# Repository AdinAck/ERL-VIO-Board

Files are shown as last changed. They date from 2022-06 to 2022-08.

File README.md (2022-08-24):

# ERL-VIO-Board
A small board intended for cleaning up the VIO sets, providing power options, and connecting the cameras and IMU.

# **WARNING**

**v1.0 has a silk screen error for the external supply port. - should be + and + should be -**

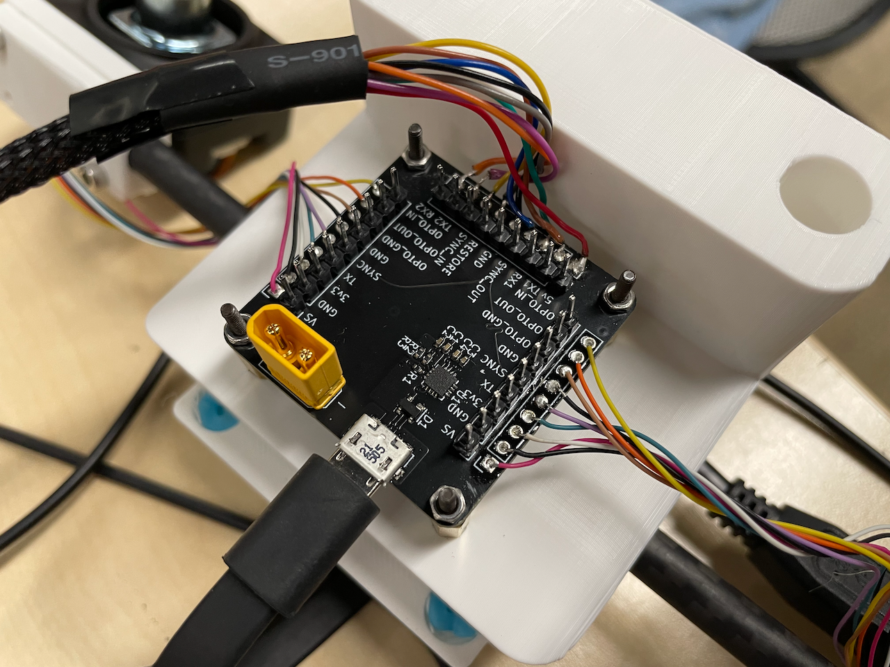
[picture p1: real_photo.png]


## Project Goal
Make it as easy and fast as possible to swap out cameras or IMU, and to diagnose problems.

## Features
- Verbose connectivity for IMU and cameras
- USB to UART bridge for IMU
- `SYNC` connection between IMU and cameras
- Optional external supply for cameras

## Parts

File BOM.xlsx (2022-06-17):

Table 1
Reference | Value | Footprint | Datasheet | Mouser | Quantity
> C1, C4 | 4u7 | Capacitor_SMD:C_0402_1005Metric | https://www.mouser.com/datasheet/2/281/1/GRM155R60J475ME87_01A-1983790.pdf | https://www.mouser.com/ProductDetail/Murata-Electronics/GRM155R60J475ME87D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 | 2
> C2, C3 | 100n | Capacitor_SMD:C_0402_1005Metric | https://www.mouser.com/datasheet/2/281/1/GRM155R71A104KA01_01A-1983947.pdf | https://www.mouser.com/ProductDetail/Murata-Electronics/GRM155R71A104KA01J | 2
D1 | SP0503BAHT | Package_TO_SOT_SMD:SOT-143 | http://www.littelfuse.com/~/media/files/littelfuse/technical%20resources/documents/data%20sheets/sp05xxba.pdf | https://www.mouser.com/ProductDetail/Littelfuse/SP0503BAHTG?qs=uD%2FdkN7XIa0NTYXwHdELYA%3D%3D | 1
J1 | Conn_01x02_Female | Connector_AMASS:AMASS_XT30U-F_1x02_P5.0mm_Vertical | ~ |  | 1
J2 | USB_B_Micro | Connector_USB:USB_Micro-B_Molex_47346-0001 | ~ | https://www.mouser.com/ProductDetail/Molex/47346-0001?qs=c2CV6XM0DweJBWaSeyWeCw%3D%3D | 1
> J3-J5 | Conn_01x09_Male | Connector_PinHeader_2.54mm:PinHeader_1x09_P2.54mm_Vertical | ~ |  | 3
> J6-J8 | Conn_01x09_Female | Connector_PinSocket_2.54mm:PinSocket_1x09_P2.54mm_Vertical | ~ |  | 3
R1 | 5k1 | Resistor_SMD:R_0402_1005Metric | https://www.mouser.com/datasheet/2/315/AOA0000C301-1488782.pdf | https://www.mouser.com/ProductDetail/Panasonic/ERJ-2RKF5101X?qs=sGAEpiMZZMvdGkrng054t8AJgcdMkx7xIXmurKOGv8o%3D | 1
R2 | 22k1 | Resistor_SMD:R_0402_1005Metric | ~ | https://www.mouser.com/ProductDetail/Panasonic/ERJ-2RKF2212X?qs=sGAEpiMZZMvdGkrng054t12mw2BDkjbP8o5TRFWNk6o%3D | 1
R3 | 47k5 | Resistor_SMD:R_0402_1005Metric | ~ | https://www.mouser.com/ProductDetail/Panasonic/ERJ-2RKF4752X | 1
U1 | CP2102N-Axx-xQFN20 | Package_DFN_QFN:SiliconLabs_QFN-20-1EP_3x3mm_P0.5mm_EP1.8x1.8mm | https://www.silabs.com/documents/public/data-sheets/cp2102n-datasheet.pdf | https://www.mouser.com/ProductDetail/Silicon-Labs/CP2102N-A02-GQFN20?qs=u16ybLDytRaG8WdlP0fT2g%3D%3D | 1

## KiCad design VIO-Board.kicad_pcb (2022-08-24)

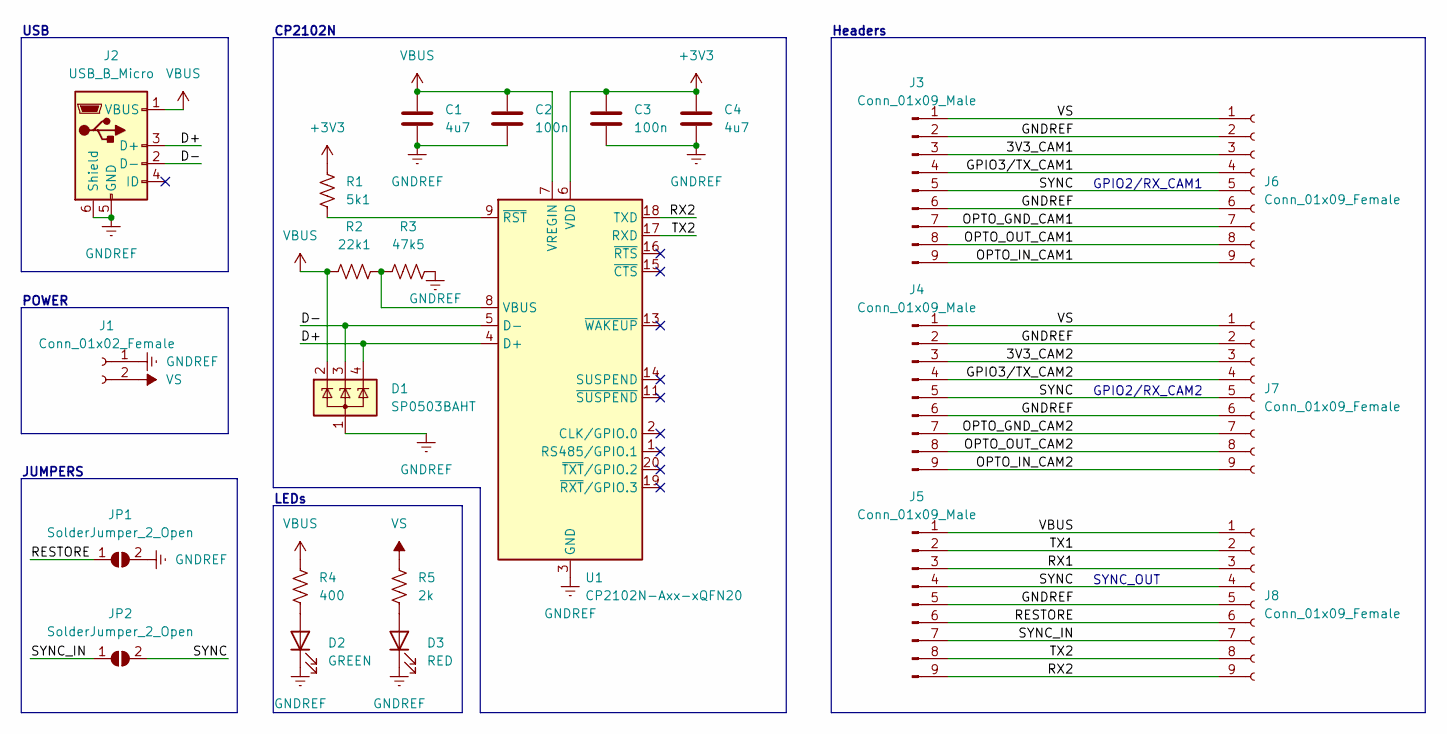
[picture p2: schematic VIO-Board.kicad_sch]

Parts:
C1, C4: 4u7; C_0402_1005Metric
C2, C3: 100n; C_0402_1005Metric
D1: SP0503BAHT; SOT-143
D2: GREEN; LED_0603_1608Metric
D3: RED; LED_0603_1608Metric
J1: Conn_01x02_Female; AMASS_XT30U-F_1x02_P5.0mm_Vertical
J2: USB_B_Micro; USB_Micro-B_Molex_47346-0001
J3, J4, J5: Conn_01x09_Male; PinHeader_1x09_P2.54mm_Vertical
J6, J7, J8: Conn_01x09_Female; PinSocket_1x09_P2.54mm_Vertical
JP1, JP2: SolderJumper_2_Open; SolderJumper-2_P1.3mm_Open_RoundedPad1.0x1.5mm
R1: 5k1; R_0402_1005Metric
R2: 22k1; R_0402_1005Metric
R3: 47k5; R_0402_1005Metric
R4: 400; R_0402_1005Metric
R5: 2k; R_0402_1005Metric
U1: CP2102N-Axx-xQFN20; SiliconLabs_QFN-20-1EP_3x3mm_P0.5mm_EP1.8x1.8mm

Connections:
+3V3: C3.1, C4.1, R1.1, U1.6 (VDD)
/3V3_CAM1: J3.3, J6.3
/3V3_CAM2: J4.3, J7.3
/D+: D1.4 (K), J2.3 (D+), U1.4 (D+)
/D-: D1.3 (K), J2.2 (D-), U1.5 (D-)
/GPIO3/TX_CAM1: J3.4, J6.4
/GPIO3/TX_CAM2: J4.4, J7.4
/OPTO_GND_CAM1: J3.7, J6.7
/OPTO_GND_CAM2: J4.7, J7.7
/OPTO_IN_CAM1: J3.9, J6.9
/OPTO_IN_CAM2: J4.9, J7.9
/OPTO_OUT_CAM1: J3.8, J6.8
/OPTO_OUT_CAM2: J4.8, J7.8
/RESTORE: J5.6, J8.6, JP1.1 (A)
/RX1: J5.3, J8.3
/RX2: J5.9, J8.9, U1.18 (TXD)
/SYNC: J3.5, J4.5, J5.4, J6.5, J7.5, J8.4, JP2.2 (B)
/SYNC_IN: J5.7, J8.7, JP2.1 (A)
/TX1: J5.2, J8.2
/TX2: J5.8, J8.8, U1.17 (RXD)
GNDREF: C1.2, C2.2, C3.2, C4.2, D1.1 (A), D2.1 (K), D3.1 (K), J1.1, J2.5 (GND), J2.6 (Shield), J3.2, J3.6, J4.2, J4.6, J5.5, J6.2, J6.6, J7.2, J7.6, J8.5, JP1.2 (B), R3.2, U1.3 (GND), U1.12 (GND), U1.21 (GND)
unnamed: D2.2 (A), R4.2
unnamed: D3.2 (A), R5.2
unnamed: R1.2, U1.9 (~RST)
unnamed: R2.2, R3.1, U1.8 (VBUS)
VBUS: C1.1, C2.1, D1.2 (K), J2.1 (VBUS), J5.1, J8.1, R2.1, R4.1, U1.7 (VREGIN)
VS: J1.2, J3.1, J4.1, J6.1, J7.1, R5.1

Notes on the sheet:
Headers
POWER
SYNC_OUT
JUMPERS
GPIO2/RX_CAM2
LEDs
USB
GPIO2/RX_CAM1
CP2102N

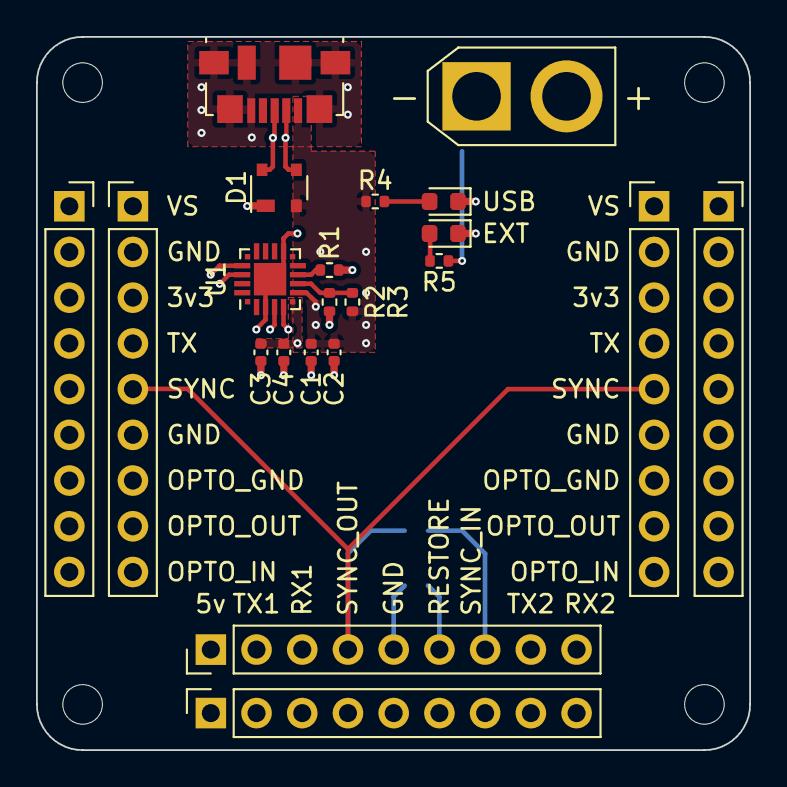
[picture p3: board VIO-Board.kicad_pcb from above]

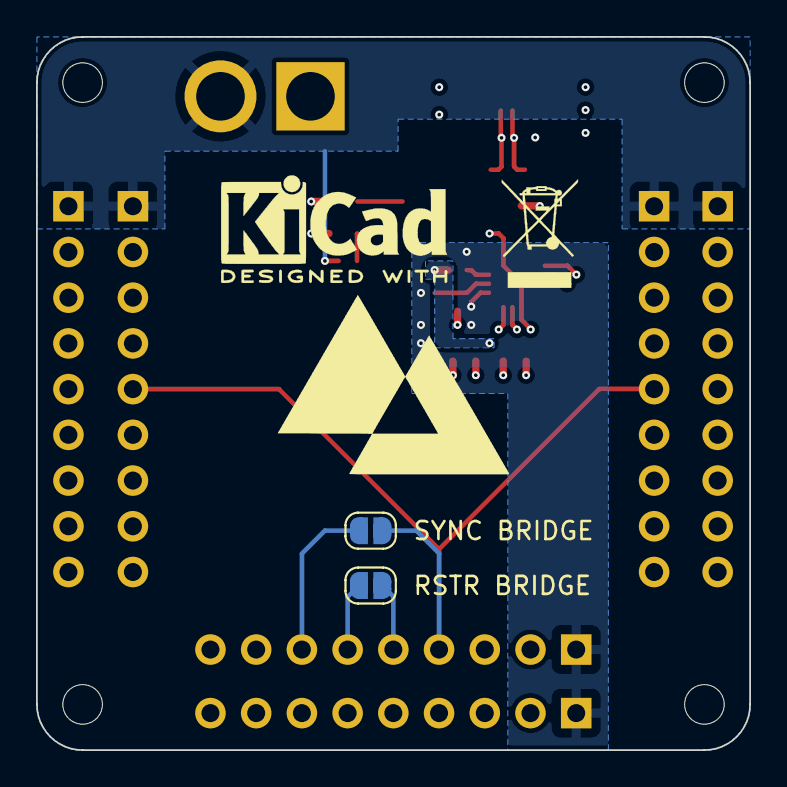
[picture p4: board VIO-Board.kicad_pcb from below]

Board: 4 copper layers, 39.6 x 39.6 mm, 23 parts (2 on the bottom side), 27 nets.

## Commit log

2022-05-06 add led
2022-05-06 add led again
    [VIO-Board.kicad_sch]
2022-06-17 new package, ESD protection, fixes
    [VIO-Board-rounded.kicad_pcb, VIO-Board.kicad_pcb]
2022-06-17 final touches
    [VIO-Board-rounded.kicad_pcb, VIO-Board.kicad_sch]
2022-06-17 BOM and corrections
    [BOM.xlsx, VIO-Board.kicad_pcb, VIO-Board.kicad_sch]
2022-06-17 gerber files, small correction
    [VIO-Board-rounded-B_Mask.gbr, VIO-Board-rounded-B_Paste.gbr, VIO-Board-rounded-B_Silkscreen.gbr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]
